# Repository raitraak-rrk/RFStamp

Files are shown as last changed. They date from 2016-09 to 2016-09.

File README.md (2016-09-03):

# RFStamp

RFStamp is a small form factor SAMR21G18 Radio Module Hardware project.

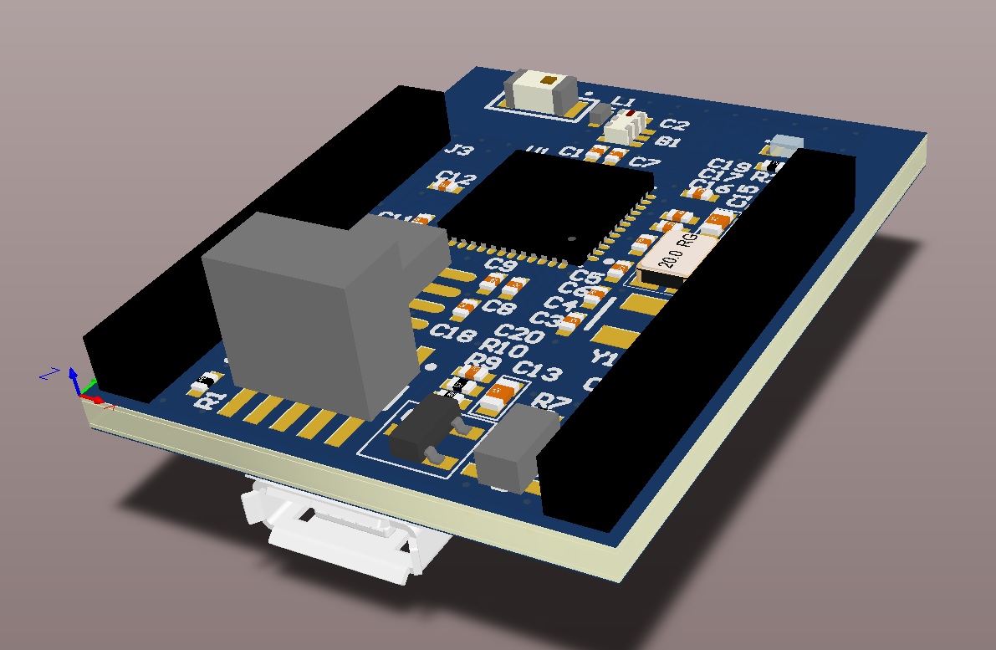
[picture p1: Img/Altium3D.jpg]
RFStamp


## Features

* SAMR21G18 MCU: Cortex M0+ CPU up to 48MHz, 256kB flash, 32kB RAM, IEEE 802.15.4 radio, capacitive touch.
* 4-Mbit DataFlash for data and firmware image storage. Up to 64Mbit pin compatible options available.
* Dual row 100mil extension header.
* Through hole or SMD mounting (no USB for SMD).
* 15 configurable GPIO/peripheral pins.
* Micro-USB connector.
* Standard 10-pin Cortex Debug connector.
* Green user LED.
* Reverse power protection.
* Supply voltage range :   1.8V - 3.3V. With LDO: up to 5.5V.
* Input voltage measurement.
* Capacitive touch pins with as much clearance as possible to minimize ground loading.

## Device Variants

* Through hole.
* SMD - No USB, as USB connector and components are placed on the bottom.

## Configuration

* USB Powered - To make the device USB powered, resistor R6 (0 ohm) needs to be mounted.
* Direct battery powered - Mount resistor R7 and remove U2. This allows to save power and voltage dropout on LDO. MCU supply voltage is 1.8V-3.3V.

## Design Environment

Device has been designed with Altium Designer 16.

## Compatibility

* Arduino Zero - As Arduino is using the same MCU (R21 = D21 + RF) it might be possible to use Arduino environment for development. This has not been investigated.

## Software

Currently no board specific software is provided.

## Software Tools and Libraries

* [Atmel Studio IDE](http://www.atmel.com/tools/ATMELSTUDIO.aspx)
* [Free ZigBee Pro stack - BitCloud](http://www.atmel.com/tools/BITCLOUD-ZIGBEEPRO.aspx)
* [IEEE 802.15.4 MAC](http://www.atmel.com/tools/IEEE802_15_4MAC.aspx)
* [SmartConnect 6LoWPAN](http://www.atmel.com/tools/SmartConnect-6LoWPAN.aspx)

## License

<br />This work is licensed under a <a rel="license" href="http://creativecommons.org/licenses/by-sa/4.0/">Creative Commons Attribution-ShareAlike 4.0 International License</a>.

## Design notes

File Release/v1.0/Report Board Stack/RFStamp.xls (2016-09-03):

Board Stack Report
Stack Up |  | Layer Stack
Layer | Board Layer Stack | Name | Material | Thickness | Constant
1 |  | Top Paste
2 |  | Top Overlay
3 |  | Top Solder | Solder Resist | 0.010mm | 3.5
4 |  | Top Layer | Copper | 0.053mm
5 |  | Dielectric1 | FR-4 | 0.180mm | 4.8
6 |  | GND | Copper | 0.032mm
7 |  | Dielectric2 | FR-4 | 1.080mm | 4.8
8 |  | POWER | Copper | 0.032mm
9 |  | Dielectric3 | FR-4 | 0.180mm | 4.8
10 |  | Bottom Layer | Copper | 0.053mm
11 |  | Bottom Solder | Solder Resist | 0.010mm | 3.5
12 |  | Bottom Overlay
13 |  | Bottom Paste
 | Height : 1.630mm

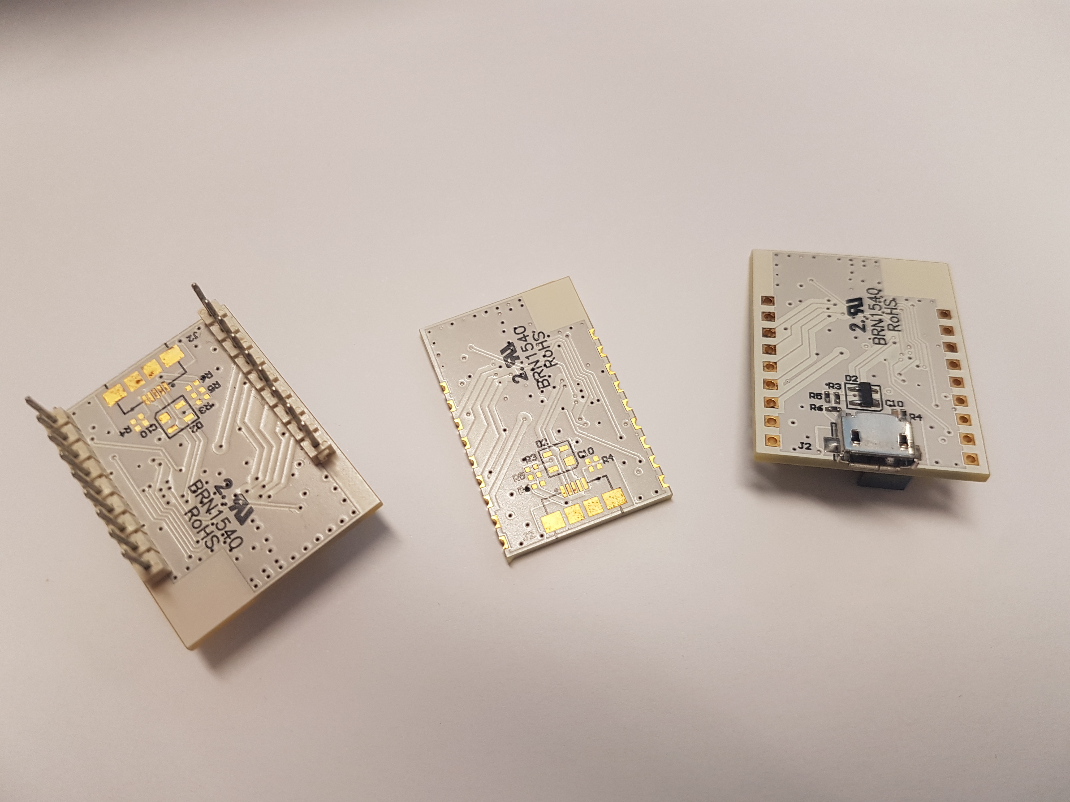
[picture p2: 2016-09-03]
Img/Boards_Bottom.jpg

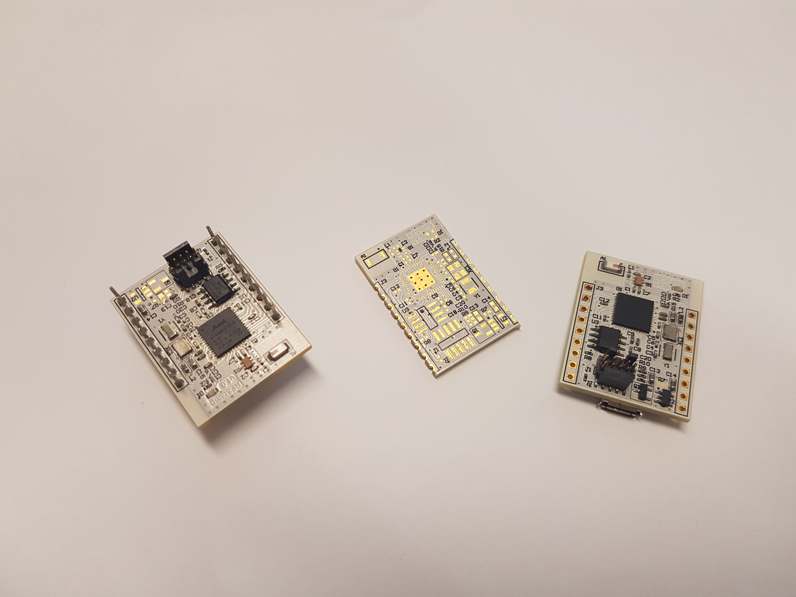
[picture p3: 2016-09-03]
Img/Boards_Top.jpg

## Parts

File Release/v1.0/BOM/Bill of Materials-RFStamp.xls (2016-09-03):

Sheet: BOM Report
Bill of Materials |  |  | Bill of Materials For Schematic Document [RFStamp.SchDoc]
Source Data From: |  | RFStamp.SchDoc
Project: |  | RFStamp.PrjPcb
Variant: |  | None
Creation Date: | 3/09/2016 | 5:07:22 PM
Print Date: | 2016-09-03 | 17:07:28
Footprint | Comment | LibRef | Designator | Description | Quantity
2450AT18A100 | 2450AT18A100 | 2450AT18A100 | A1 | Ceramic 2.45 GHz Antenna | 1
AP3-00060 | 2450BM15A0015E | A03-0091 | B1 | Filtered Balun to match AT86RF232/233 (35288) | 1
AP1-00053 | 22p | A01-0246 | C1, C7 | Ceramic capacitor, SMD 0402, X7R, 16V, +/-10% | 2
AP1-00053 | 1.5p | A01-0246 | C2 | Ceramic capacitor, SMD 0402, X7R, 16V, +/-10% | 1
AP1-00053 | 12p | A01-0246 | C3, C4 | Ceramic capacitor, SMD 0402, X7R, 16V, +/-10% | 2
AP1-00053 | 10p | A01-0246 | C5, C6 | Ceramic capacitor, SMD 0402, X7R, 16V, +/-10% | 2
AP1-00053 | 100n | A01-0246 | C8, C9, C11, C12, C16, C17, C18, C19, C20 | Ceramic capacitor, SMD 0402, X7R, 16V, +/-10% | 9
AP1-00053 | 4.7n | A01-0046 | C10 | Ceramic capacitor, SMD 0402, X7R, 25V, +/-10% | 1
AP1-00039 | 1uF | A01-0377 | C13, C14 | Ceramic capacitor, SMD 0603, X5R, 10V, 10% (de31036), Ceramic capacitor, SMD 0603, X5R, 6.3V, 10% | 2
AP1-00039 | 10uF/16V | A01-0491 | C15 | Ceramic capacitor, SMD 0603, X5R, 16V, 10UF ± 20% (High Density) | 1
LS L29K | LT L29S-P2R1-25-Z |  | D1 |  | 1
AP4-00001 | PRTR5V0U2X | A06-0236 | D2 | Double rail-to-rail USB ESD protection diode | 1
FTSH_SMT_10 | FTSH-105 |  | J1 | CONN HEADER 10POS DUAL .05" SMD | 1
AP8-00604 | 10104111-0001LF | A08-1368 | J2 | Micro USB AB Connector | 1
0402-A | 3.3nH | Inductor | L1 | Inductor | 1
AP3-00005 | BLM18PG471SN1 | A03-0035 | L2 | SMD RF inductor 0603. Z=470Ohm (@100MHz), Max R(dc)=0.65Ohm, Max current=1A | 1
AP5-00002 | IRLML6402PBF | A05-0087 | Q1 | P-ch. MOSFET. -30V, -3.7A continuous,RDS(ON)=0.05Ohm@VGS=-4,5V, RDS(ON)=0.08Ohm@VGS=-2.5V | 1
AP2-00011 | 10k | A02-0252, A02-0284 | R1, R8 | Thick film resistor, SMD 0402, 1/16W, 5% | 2
AP2-00011 | 330R | A02-0200 | R2 | Thick film resistor, SMD 0402, 1/16W, 5% | 1
AP2-00011 | 100k | A02-0252 | R3, R5, R9, R10 | Thick film resistor, SMD 0402, 1/16W, 5% | 4
AP2-00011 | 1M | A02-0284 | R4 | Thick film resistor, SMD 0402, 1/16W, 5% | 1
AP2-00011 | 0R | A02-0252 | R6 | Thick film resistor, SMD 0402, 1/16W, 5% | 1
AP6-00171 | SAMR21G18A-MUT |  | U1 | Atmel 32-bit Cortex M0+ MCU with RF233 SIP. | 1
TI-DBV5_N | TLV71333PDBVR | TLV70233DBVR | U2 | Single Output LDO, 150 mA, Fixed 3.3 V Output, 2 to 5.5 V Input, with Low IQ, 5-pin SOT-23 (DBV), -40 to 85 degC, Green (RoHS & no Sb/Br) | 1
8S1_N | AT45DB041E-SSHN-B | AT45DB041E | U3 | 4-Mbit DataFlash (with Extra 128-Kbits), 1.65V Minimum SPI Serial Flash Memory, 8-Pin SOIC | 1
AP7-00061 | TSX-3225 |  | XC1 | 16MHz uXtal, 3.2 x 2.5 mm SMD, CL=9pF, 15PPM, ESR=80ohm(Max. | 1
ABS07 | ABS07-32.768KHZ-7-T | ABS07 | Y1 | Low Profile Surface Mount Crystal | 1
 |  |  |  |  | 43
Approved |  | Notes

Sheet: Project Information
Project Full Path | C:\Users\rait.raak\Desktop\rfstamp\RFStamp\RFStamp.PrjPcb
Project Filename | RFStamp.PrjPcb
Variant Name | None
Data-Source Filename | RFStamp.SchDoc
Data-Source Full Path | C:\Users\rait.raak\Desktop\rfstamp\RFStamp\RFStamp.SchDoc
Title | Bill of Materials For Schematic Document [RFStamp.SchDoc]
Total Quantity | 43
Report Time | 5:07:22 PM
Report Date | 3/09/2016
Report Date & Tine | 3/09/2016 5:07:22 PM
Output Name | Bill of Materials
Output Type | BOM_PartType
Output Generator Name | BOM
Output Generator Description | Bill of Materials

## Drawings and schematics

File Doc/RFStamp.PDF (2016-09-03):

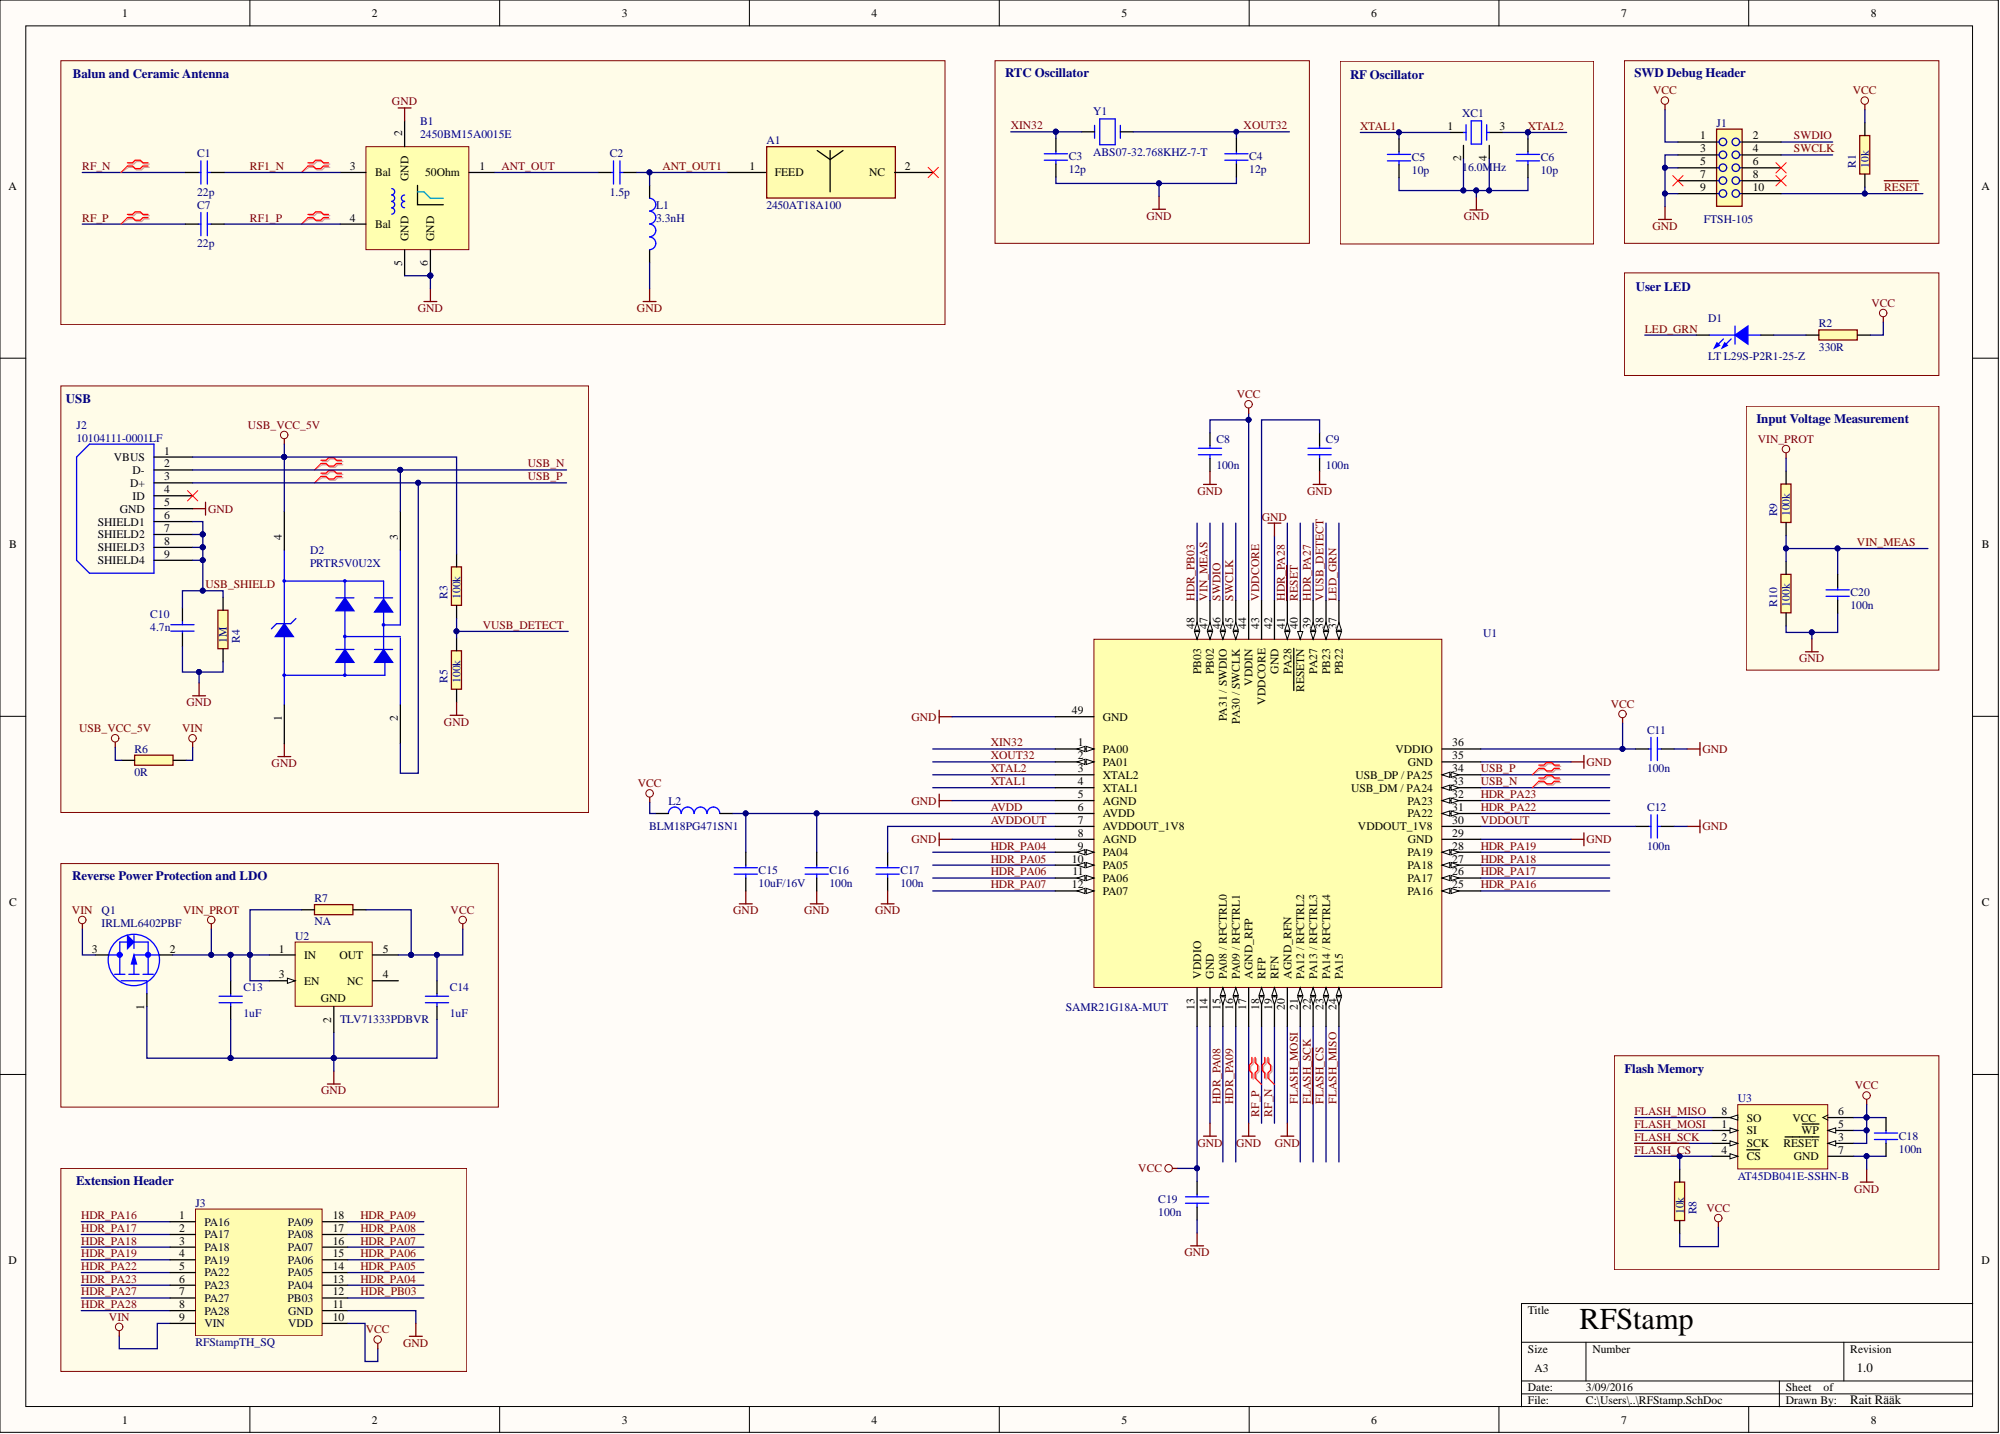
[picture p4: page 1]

Balun and Ceramic Antenna

PB22 37 PB23 38 PA27 39 RESETN 40 PA28 41 GND 42 VDDCORE 43 VDDIN 44 PA30 / SWCLK 45 PA31 / SWDIO 46 PB02 47 PB03 48

Reverse Power Protection and LDO

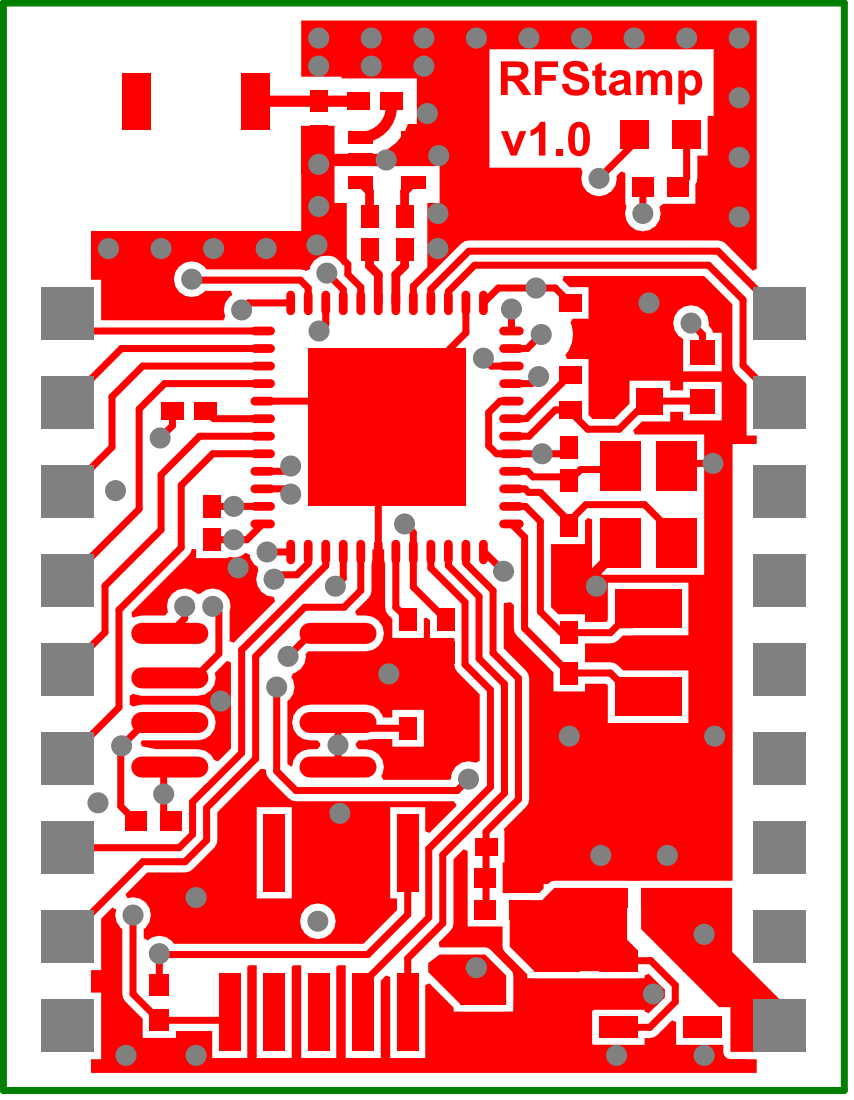
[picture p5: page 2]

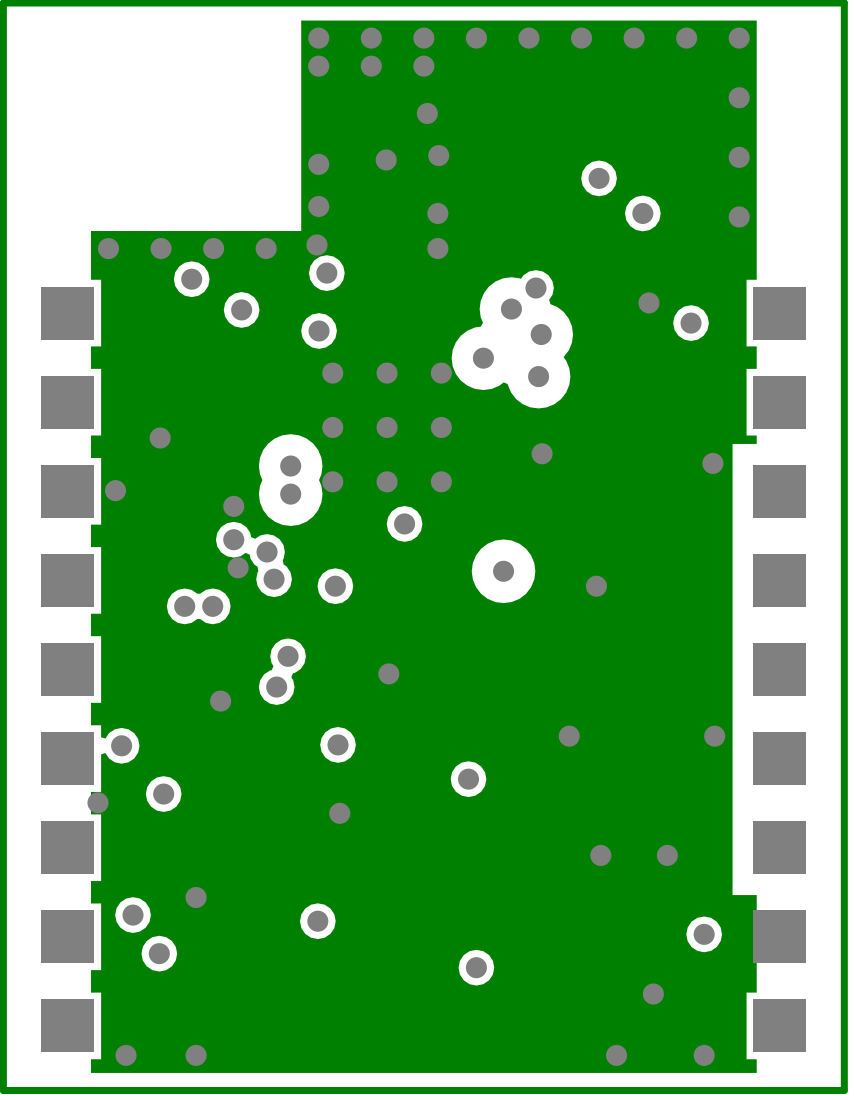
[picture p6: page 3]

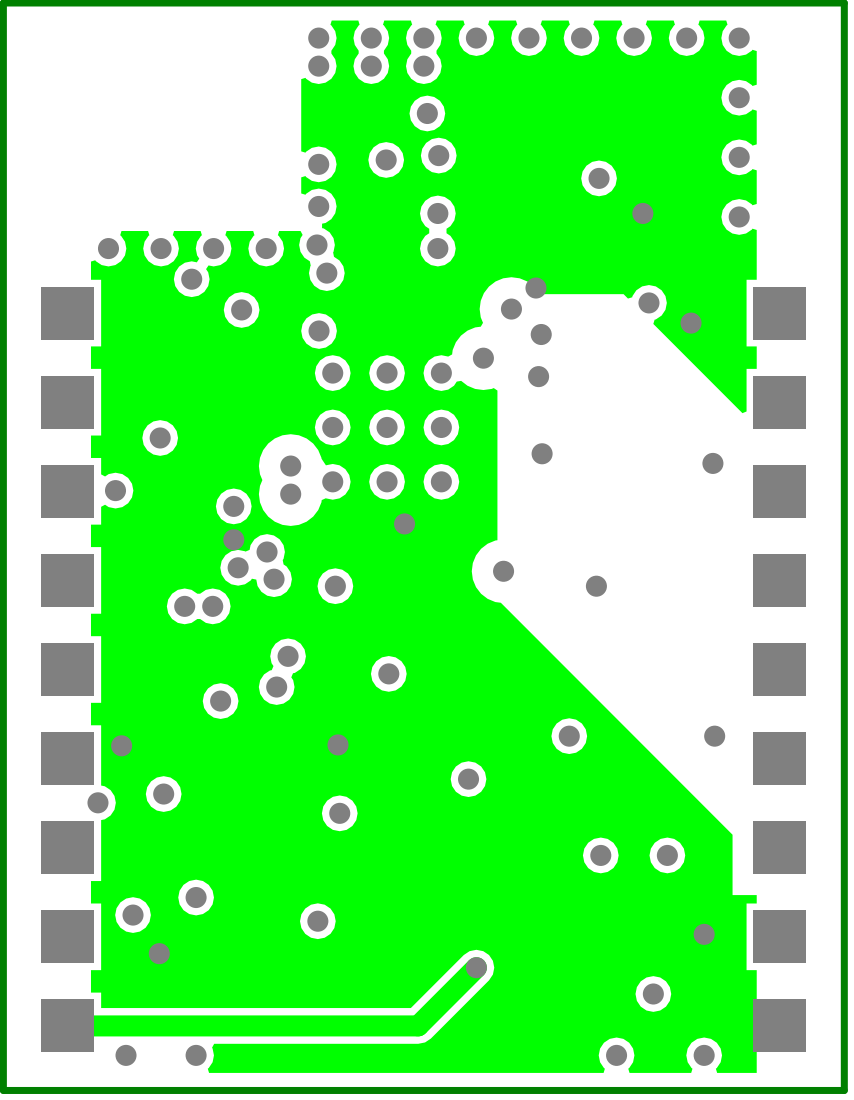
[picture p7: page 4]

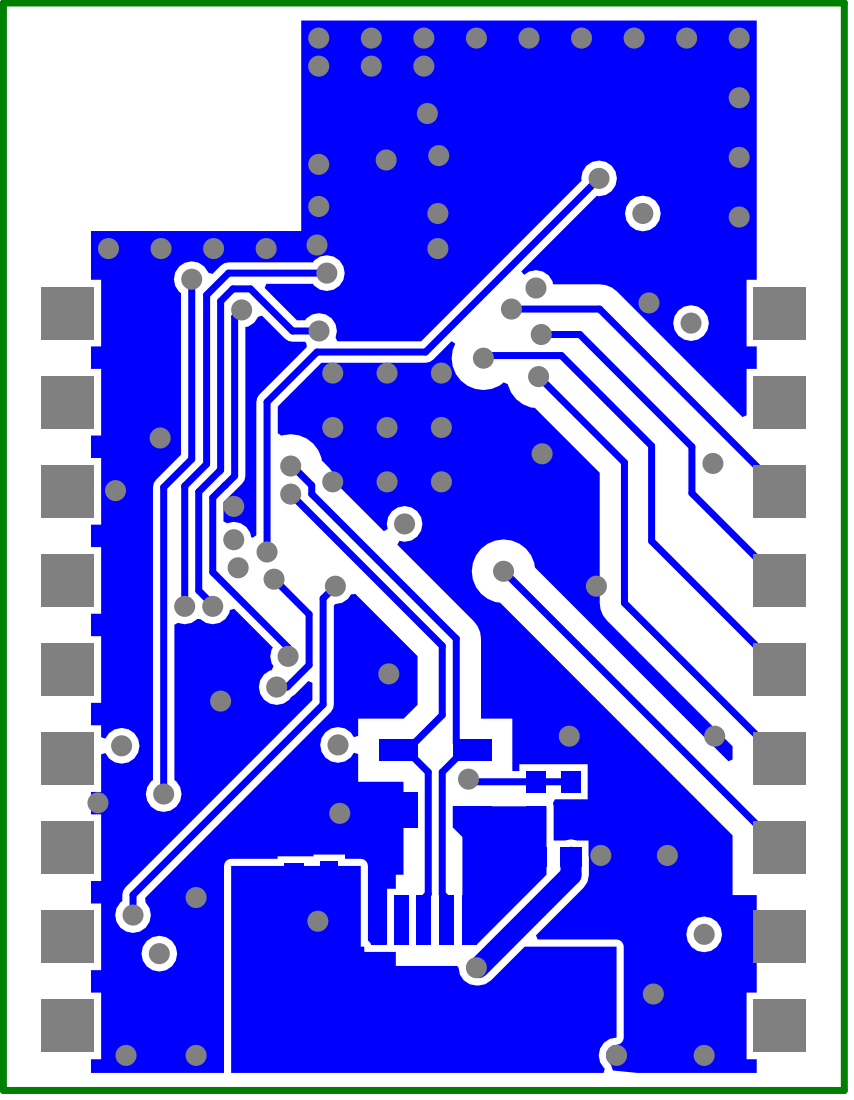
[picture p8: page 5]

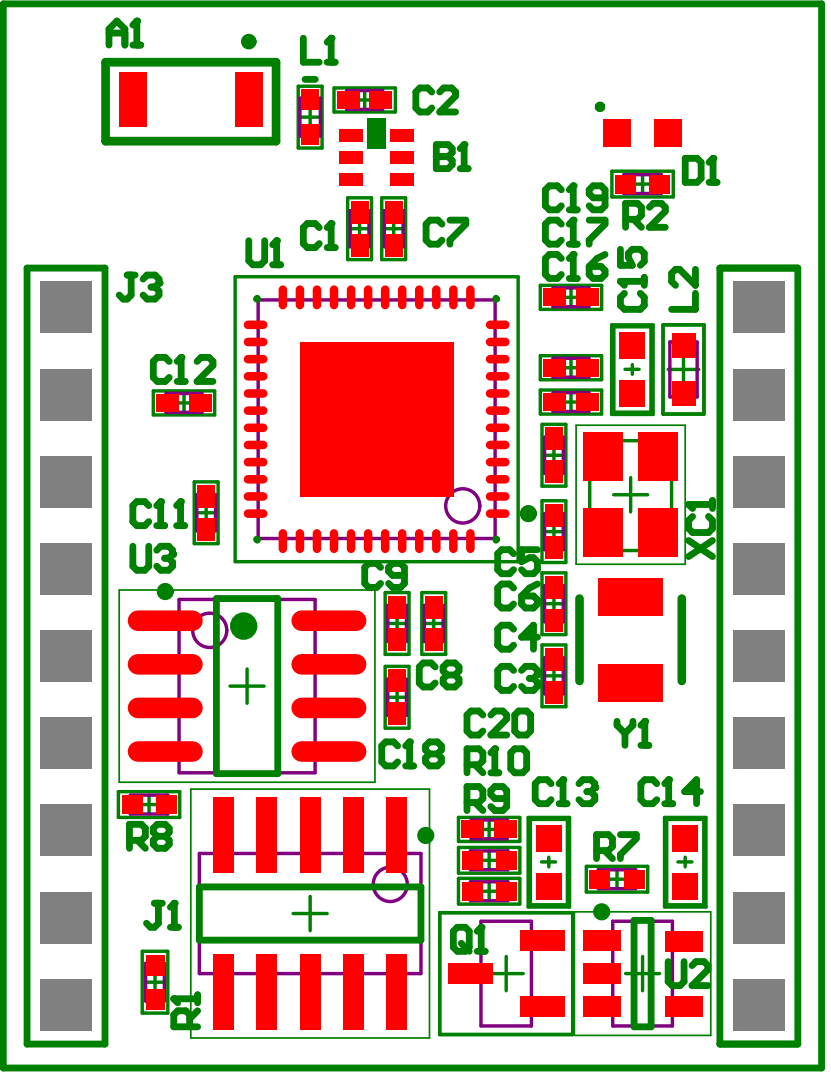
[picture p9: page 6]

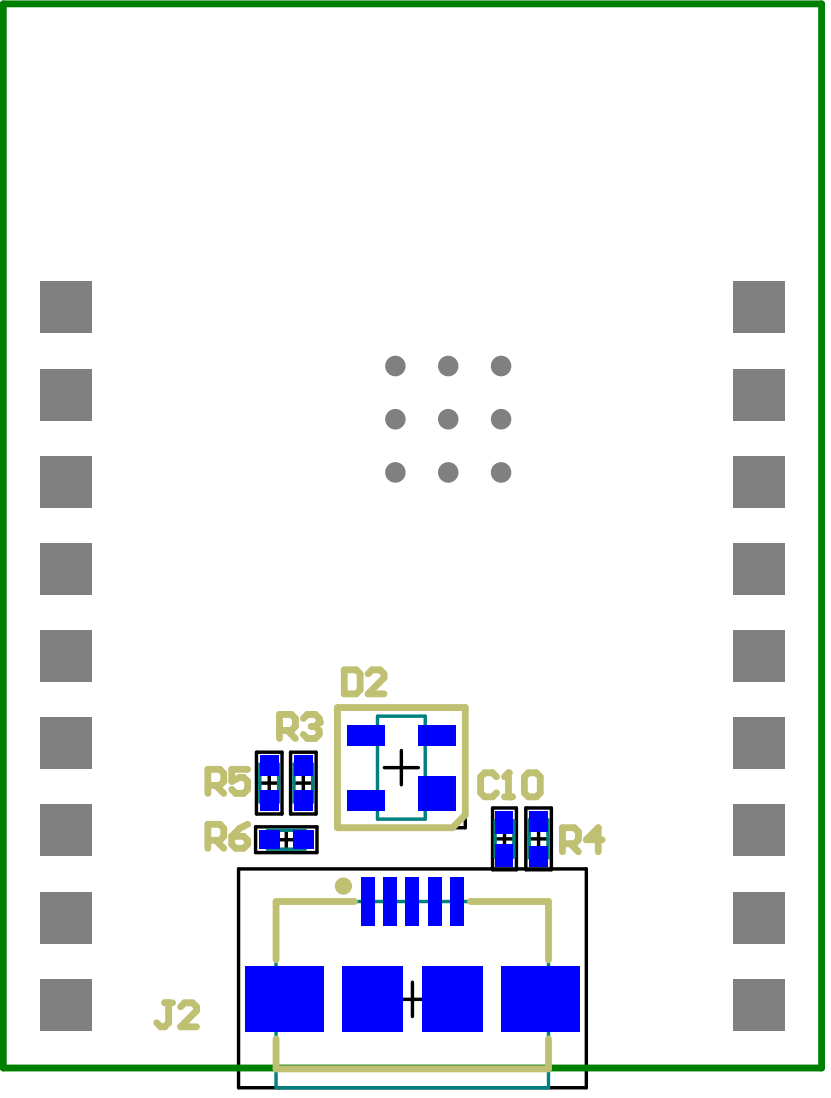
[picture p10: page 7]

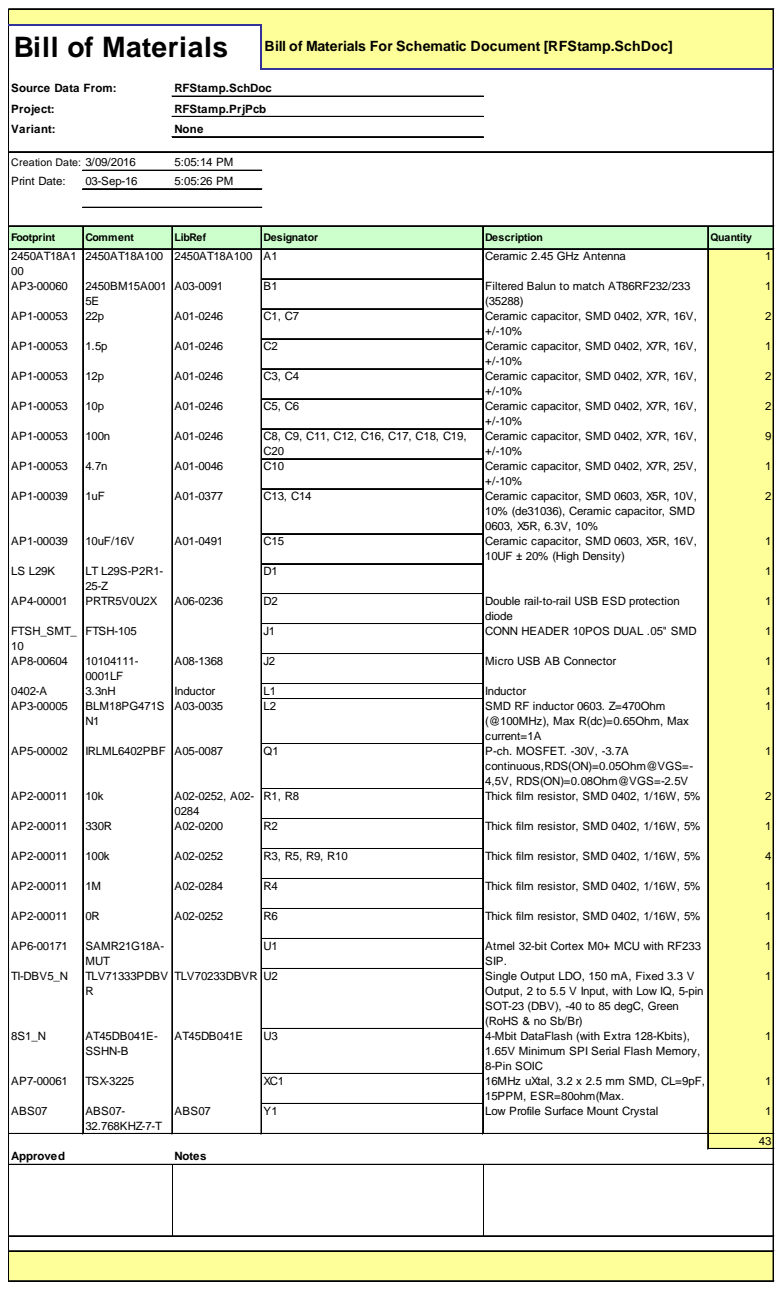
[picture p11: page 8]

continuous,RDS(ON)=0.05Ohm@VGS=-
4,5V, RDS(ON)=0.08Ohm@VGS=-2.5V

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

1.65V Minimum SPI Serial Flash Memory,
8-Pin SOIC
